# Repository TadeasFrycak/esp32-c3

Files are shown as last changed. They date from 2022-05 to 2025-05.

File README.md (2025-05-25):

# ESP32-C3 Nano

:warning: **Temporary warning**: This version of PCB has not been yet validated and it is actively being worked on

Compact and minimalist **ESP32-C3** breakout designed in [KiCAD](https://www.kicad.org/)

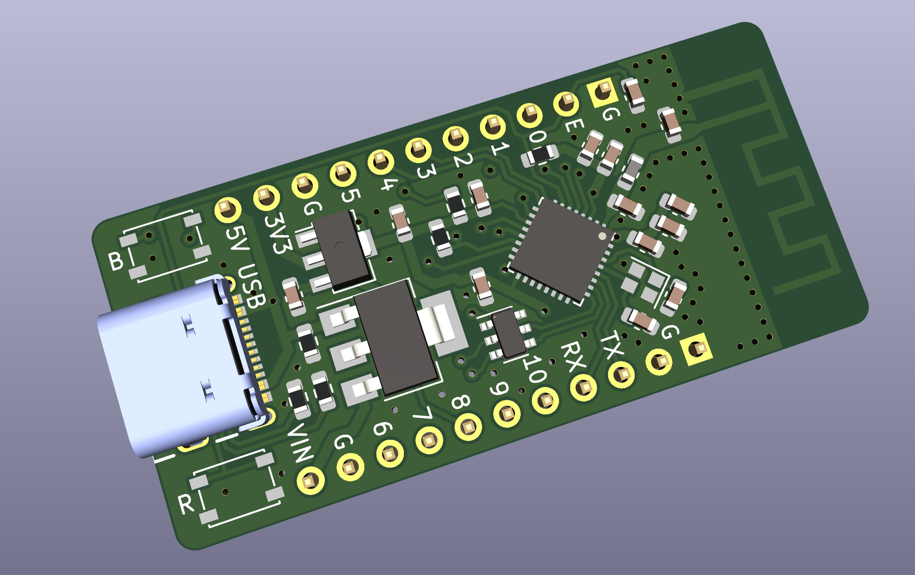
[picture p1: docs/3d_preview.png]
Preview


## Features
- **Breadboard friendly**
- **Compact dimensions** - 46 x 21.5 mm
- **USB-C** connector for programming (using CDC, so no external usb-serial convertor)
- **External VIN pin** with schottky diode (so both VIN and USB power can be applied at the same time)
- **Low dropout regulator to 3V3** (LDO)
- **Reset** and **Boot** buttons on board
- **Integrated PCB antenna**
- **USB ESD protection**
- Chip: **ESP32-C3FH4**

## Interactive HTML BOM
Thanks to the awesome KiCAD [IBOM](https://github.com/openscopeproject/InteractiveHtmlBom) plugin, we can now generate this stunning BOM! You can find it in docs/ibom.html
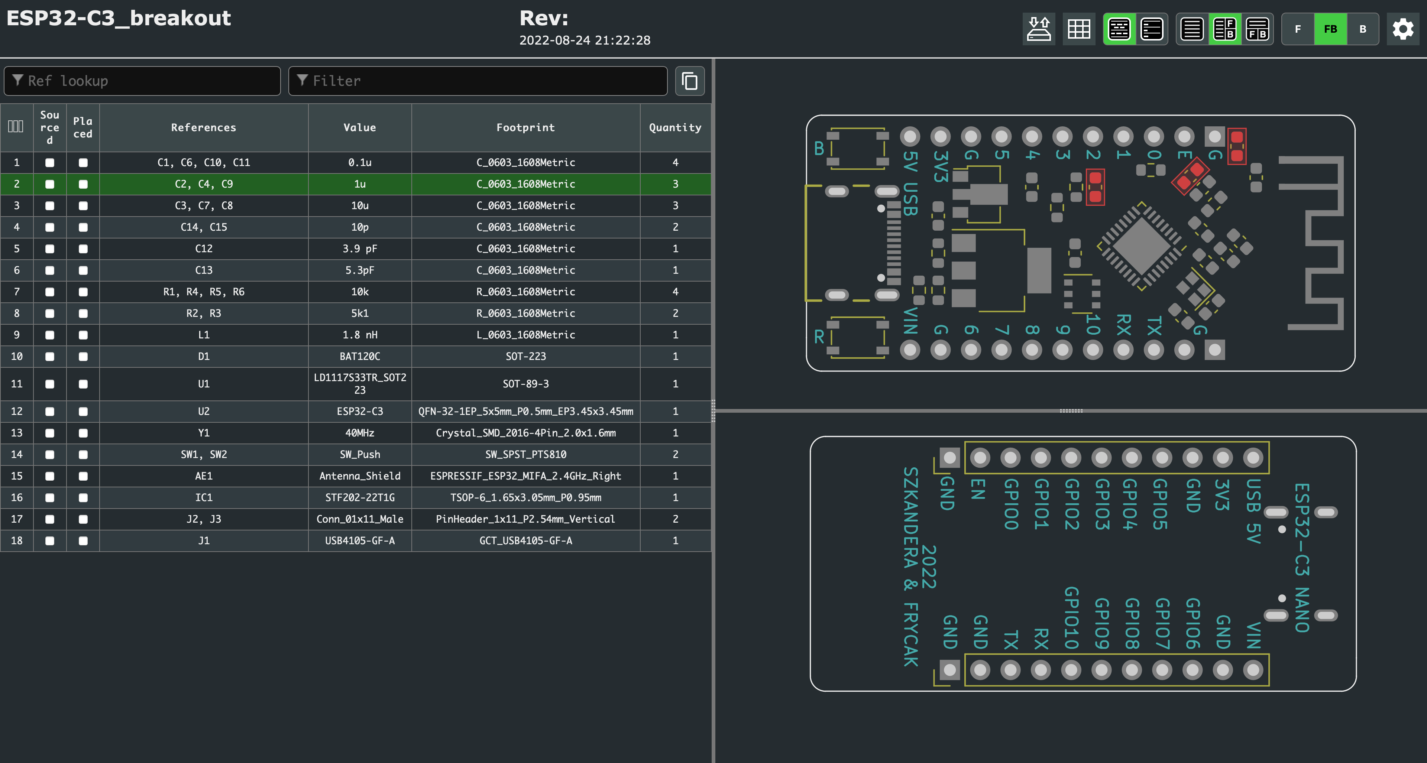
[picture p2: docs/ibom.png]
IBOM


## Schematics
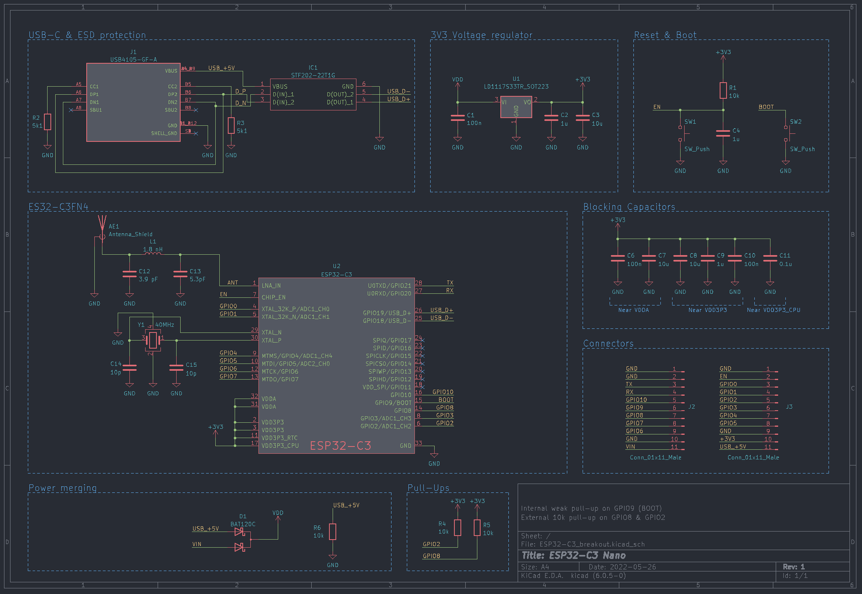
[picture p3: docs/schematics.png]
schematics


## Contributors:
- **SZKANDERA Filip** (filip.szkandera@gmail.com, [@FilipSzkandera](https://github.com/FilipSzkandera/))
- **FRYČÁK Tadeáš** (info@frycak.com, [@TadeasFrycak](https://github.com/TadeasFrycak/))

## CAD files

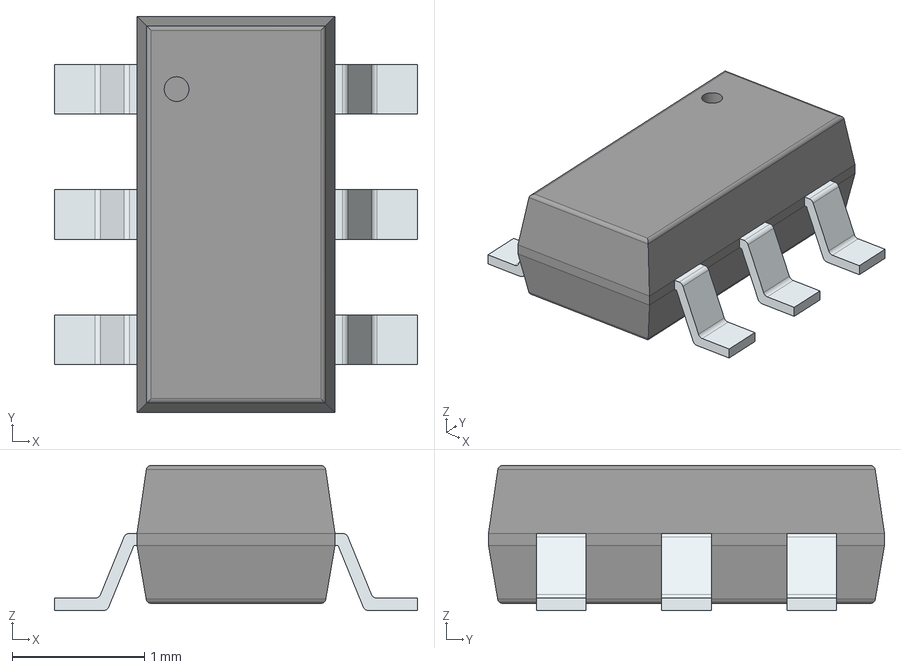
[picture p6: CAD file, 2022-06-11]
LIB_STF202-22T1G/STF202-22T1G/3D/STF202-22T1G.stp
2.75 x 3.00 x 1.10 mm
PinsArrayLR

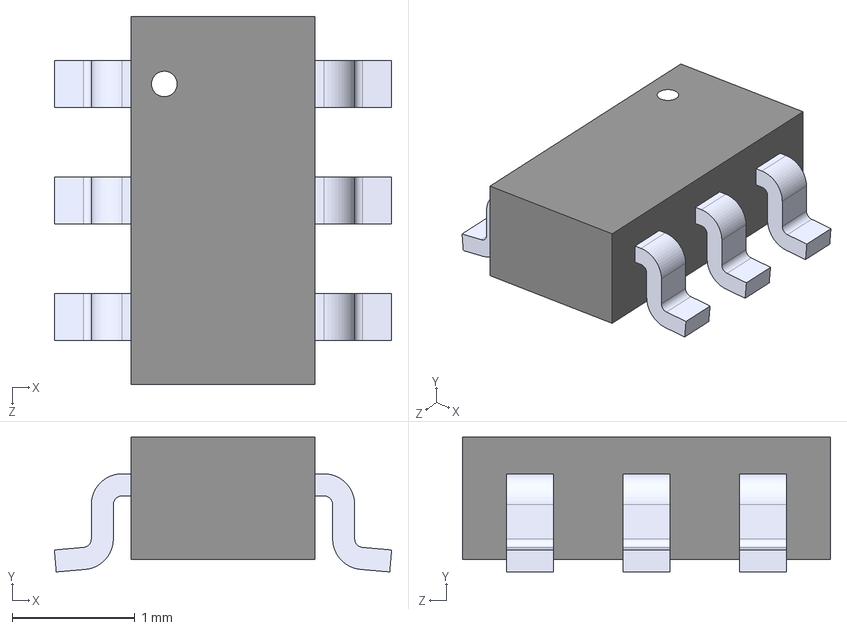
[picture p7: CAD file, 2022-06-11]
STF202-22T1G/STF202-22T1G.step
2.75 x 1.10 x 3.00 mm

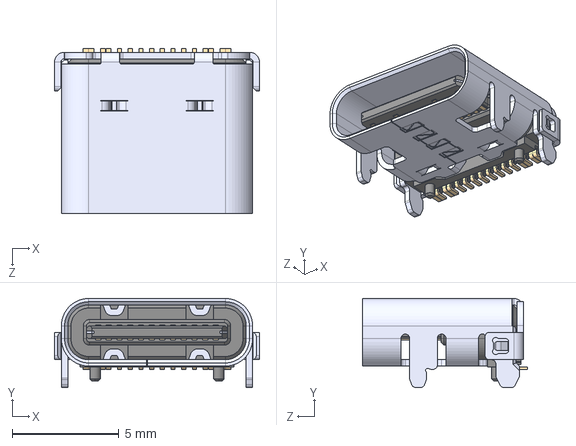
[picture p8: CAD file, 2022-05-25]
USB4105-GF-A/USB4105-GF-A.step
9.58 x 4.16 x 7.71 mm

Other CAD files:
LIB_STF202-22T1G/STF202-22T1G/3D/STF202-22T1G.stl
LIB_STF202-22T1G/STF202-22T1G/Allegro/sot95p275x110-6n.psm
LIB_STF202-22T1G/STF202-22T1G/DEHDL/stf202_22t1g/chips/chips.prt

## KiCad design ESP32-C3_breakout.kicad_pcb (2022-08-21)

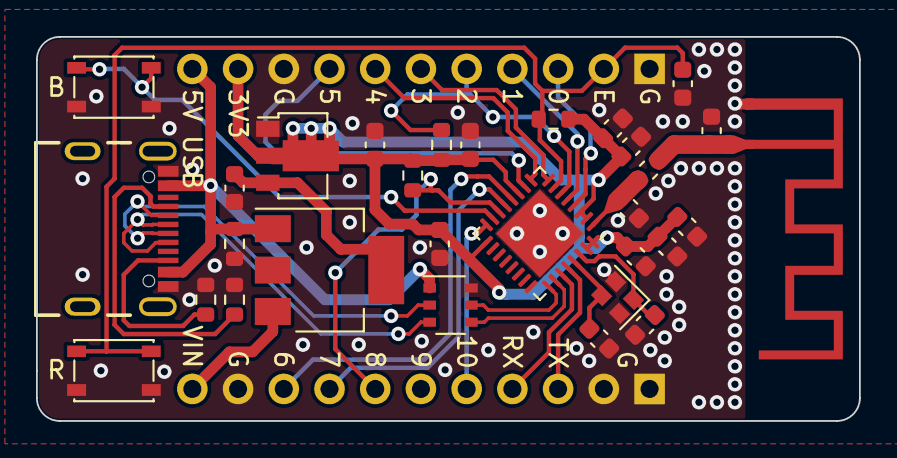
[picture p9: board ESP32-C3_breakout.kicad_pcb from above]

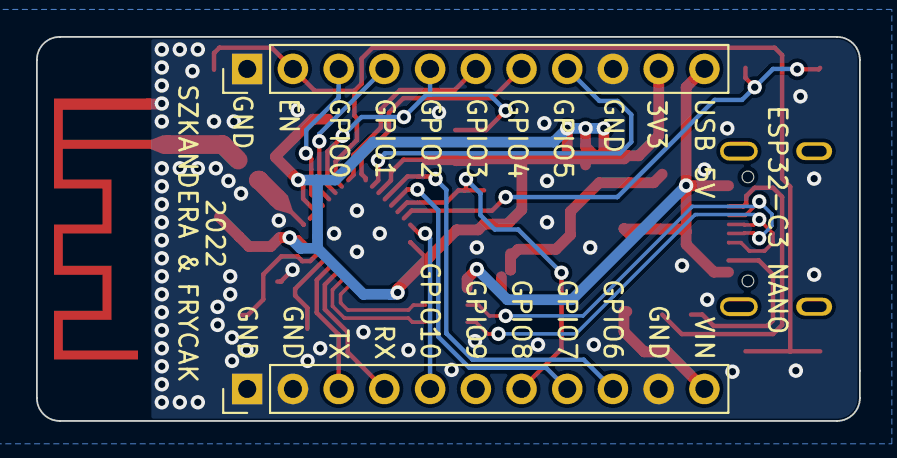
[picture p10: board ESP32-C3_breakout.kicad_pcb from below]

Board: 2 copper layers, 45.7 x 21.3 mm, 32 parts (2 on the bottom side), 29 nets.

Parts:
AE1: Antenna_Shield; ESPRESSIF_ESP32_MIFA_2.4GHz_Right
C1, C6, C10: 100n; C_0603_1608Metric
C2, C4, C9: 1u; C_0603_1608Metric
C3, C7, C8: 10u; C_0603_1608Metric
C11: 0.1u; C_0603_1608Metric
C12: 3.9 pF; C_0603_1608Metric
C13: 5.3pF; C_0603_1608Metric
C14, C15: 10p; C_0603_1608Metric
D1: BAT120C; SOT-223
IC1: STF202-22T1G; TSOP-6_1.65x3.05mm_P0.95mm
J1: USB4105-GF-A; GCT_USB4105-GF-A
J2, J3: Conn_01x11_Male; PinHeader_1x11_P2.54mm_Vertical
L1: 1.8 nH; L_0603_1608Metric
R1, R4, R5, R6: 10k; R_0603_1608Metric
R2, R3: 5k1; R_0603_1608Metric
SW1, SW2: SW_Push; SW_SPST_PTS810
U1: LD1117S33TR_SOT223; SOT-89-3
U2: ESP32-C3; QFN-32-1EP_5x5mm_P0.5mm_EP3.45x3.45mm
Y1: 40MHz; Crystal_SMD_2016-4Pin_2.0x1.6mm

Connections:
+3V3: C2.1, C3.1, C6.1, C7.1, C8.1, C9.1, C10.1, C11.1, J3.10, R1.1, R4.1, R5.1, U1.2 (VO), U2.2 (VDD3P3), U2.3 (VDD3P3), U2.11 (VDD3P3_RTC), U2.17 (VDD3P3_CPU), U2.31 (VDDA), U2.32 (VDDA)
/ANT: C13.1, L1.1, U2.1 (LNA_IN)
/BOOT: SW2.1, U2.15 (GPIO9/BOOT)
/D_N: IC1.2 (D(IN)_1), J1.A7 (DN1), J1.B7 (DN2)
/D_P: IC1.3 (D(IN)_2), J1.A6 (DP1), J1.B6 (DP2)
/EN: C4.1, J3.2, R1.2, SW1.1, U2.7 (CHIP_EN)
/GPIO0: J3.3, U2.4 (XTAL_32K_P/ADC1_CH0)
/GPIO1: J3.4, U2.5 (XTAL_32K_N/ADC1_CH1)
/GPIO2: J3.5, R4.2, U2.6 (GPIO2/ADC1_CH2)
/GPIO3: J3.6, U2.8 (GPIO3/ADC1_CH3)
/GPIO4: J3.7, U2.9 (MTMS/GPIO4/ADC1_CH4)
/GPIO5: J3.8, U2.10 (MTDI/GPIO5/ADC2_CH0)
/GPIO6: J2.9, U2.12 (MTCK/GPIO6)
/GPIO7: J2.8, U2.13 (MTDO/GPIO7)
/GPIO8: J2.7, R5.2, U2.14 (GPIO8)
/GPIO10: J2.5, U2.16 (GPIO10)
/RX: J2.4, U2.27 (U0RXD/GPIO20)
/TX: J2.3, U2.28 (U0TXD/GPIO21)
/USB_+5V: D1.1 (A1), IC1.1 (VBUS), J1.A4_B9 (VBUS), J1.B4_A9 (VBUS), J3.11, R6.1
/USB_D+: IC1.4 (D(OUT)_1), U2.26 (GPIO19/USB_D+)
/USB_D-: IC1.5 (D(OUT)_2), U2.25 (GPIO18/USB_D-)
/VIN: D1.3 (A2), J2.11
GND: AE1.2 (Shield), C1.2, C2.2, C3.2, C4.2, C6.2, C7.2, C8.2, C9.2, C10.2, C11.2, C12.2, C13.2, C14.2, C15.2, IC1.6 (GND), J1.A1_B12 (GND), J1.B1_A12 (GND), J2.1, J2.2, J2.10, J3.1, J3.9, R2.2, R3.2, R6.2, SW1.2, SW2.2, U1.1 (GND), U2.33 (GND), Y1.2, Y1.4
unnamed: AE1.1 (A), C12.1, L1.2
unnamed: C14.1, U2.29 (XTAL_N), Y1.3
unnamed: C15.1, U2.30 (XTAL_P), Y1.1
unnamed: J1.A5 (CC1), R2.1
unnamed: J1.B5 (CC2), R3.1
VDD: C1.1, D1.4 (K), U1.3 (VI)

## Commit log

2022-05-25 Added LDO
    [ESP32-C3_breakout.kicad_pcb, ESP32-C3_breakout.kicad_sch]
2022-05-25 Added USB-C
    [ESP32-C3_breakout.kicad_pcb, ESP32-C3_breakout.kicad_sch, USB4105-GF-A.step]
2022-05-25 General improvements
    [ESP32-C3_breakout.kicad_pcb, ESP32-C3_breakout.kicad_sch]
2022-05-26 Improved schematics
    [ESP32-C3_breakout.kicad_pcb, ESP32-C3_breakout.kicad_sch]
2022-05-29 Further improvements
    [ESP32-C3_breakout.kicad_pcb, ESP32-C3_breakout.kicad_sch]
2022-05-29 add: datasheets, distributors
    [ESP32-C3_breakout.kicad_sch]
2022-05-29 add: antenna π matching network values
    values, datasheets, distributors
    [ESP32-C3_breakout.kicad_sch]
2022-05-29 edit: ESP32C3FH4 distributor
    [ESP32-C3_breakout.kicad_sch]
2022-06-01 Differential pair routing change
    [ESP32-C3_breakout.kicad_pcb]
2022-06-01 Minor improvements
    [ESP32-C3_breakout.kicad_pcb, ESP32-C3_breakout.kicad_sch]
2022-06-11 Power plane improvement
    [ESP32-C3_breakout.kicad_pcb, ESP32-C3_breakout.kicad_sch]
2022-08-21 Version 2
    [ESP32-C3_breakout-B_Cu.gbr, ESP32-C3_breakout-B_Mask.gbr, ESP32-C3_breakout-B_Paste.gbr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]
2022-08-24 Added interactive BOM
2022-08-25 Added schematic image
